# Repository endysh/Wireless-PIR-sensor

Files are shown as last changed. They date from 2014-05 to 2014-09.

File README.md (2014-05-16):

Wireless-PIR-sensor
===================

The project was stared with a goal of creating a low-cost wireless PIR sensor by using Arduino compatible hardware and enclosure from already available cheap, less than $5, PIR lights you can find on eBay, like the following 
http://www.ebay.com/sch/i.html?_from=R40&_sacat=0&_nkw=wireless+pir+light+battery&_sop=15

### Features
- custom Arduino compatible hardware
- nrf24L01 2.4 GHz wireless module for communication
- 2+ years run time with 2 AA batteries

### Images

Top<br>
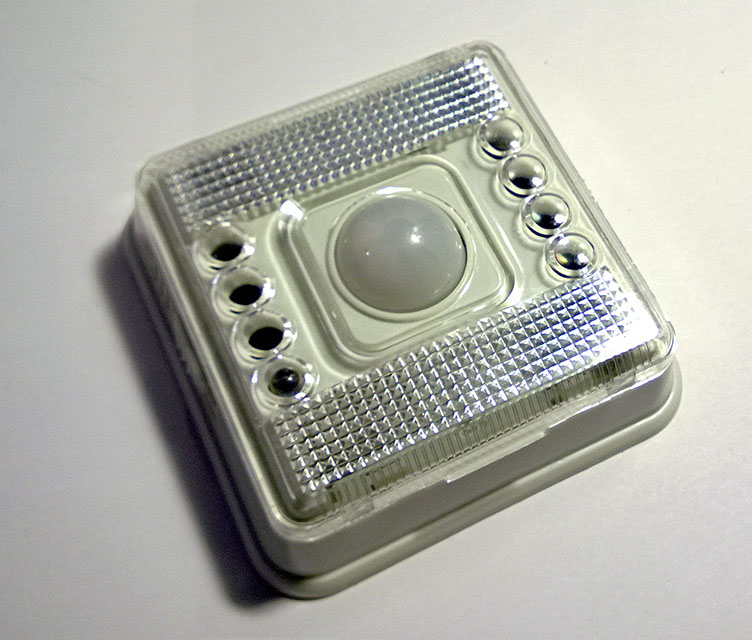
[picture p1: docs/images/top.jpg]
Top


Back with PCB visible<br>
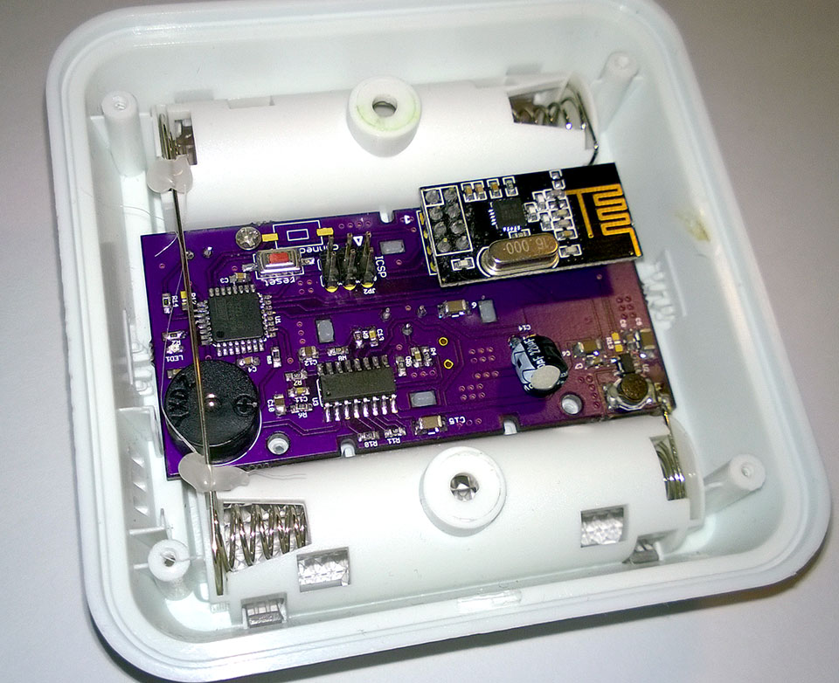
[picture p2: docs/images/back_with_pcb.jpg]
Back with PCB


Unpopulated 2-layer PCB, front and back<br>
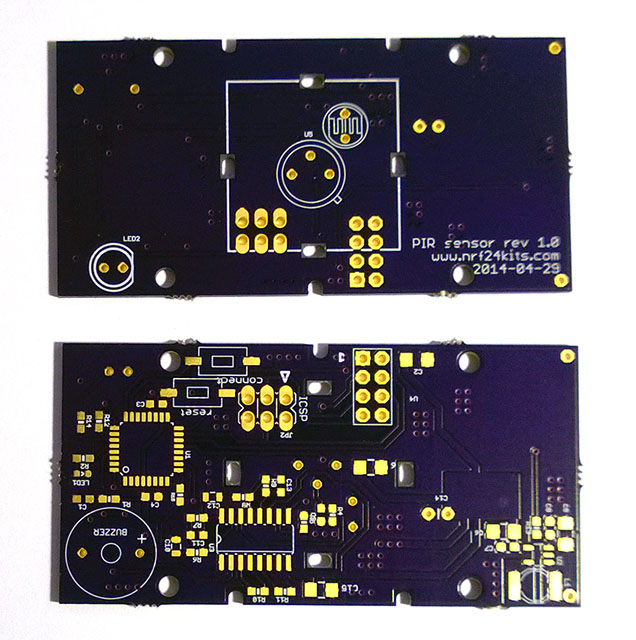
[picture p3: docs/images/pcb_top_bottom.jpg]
PCB top and bottom


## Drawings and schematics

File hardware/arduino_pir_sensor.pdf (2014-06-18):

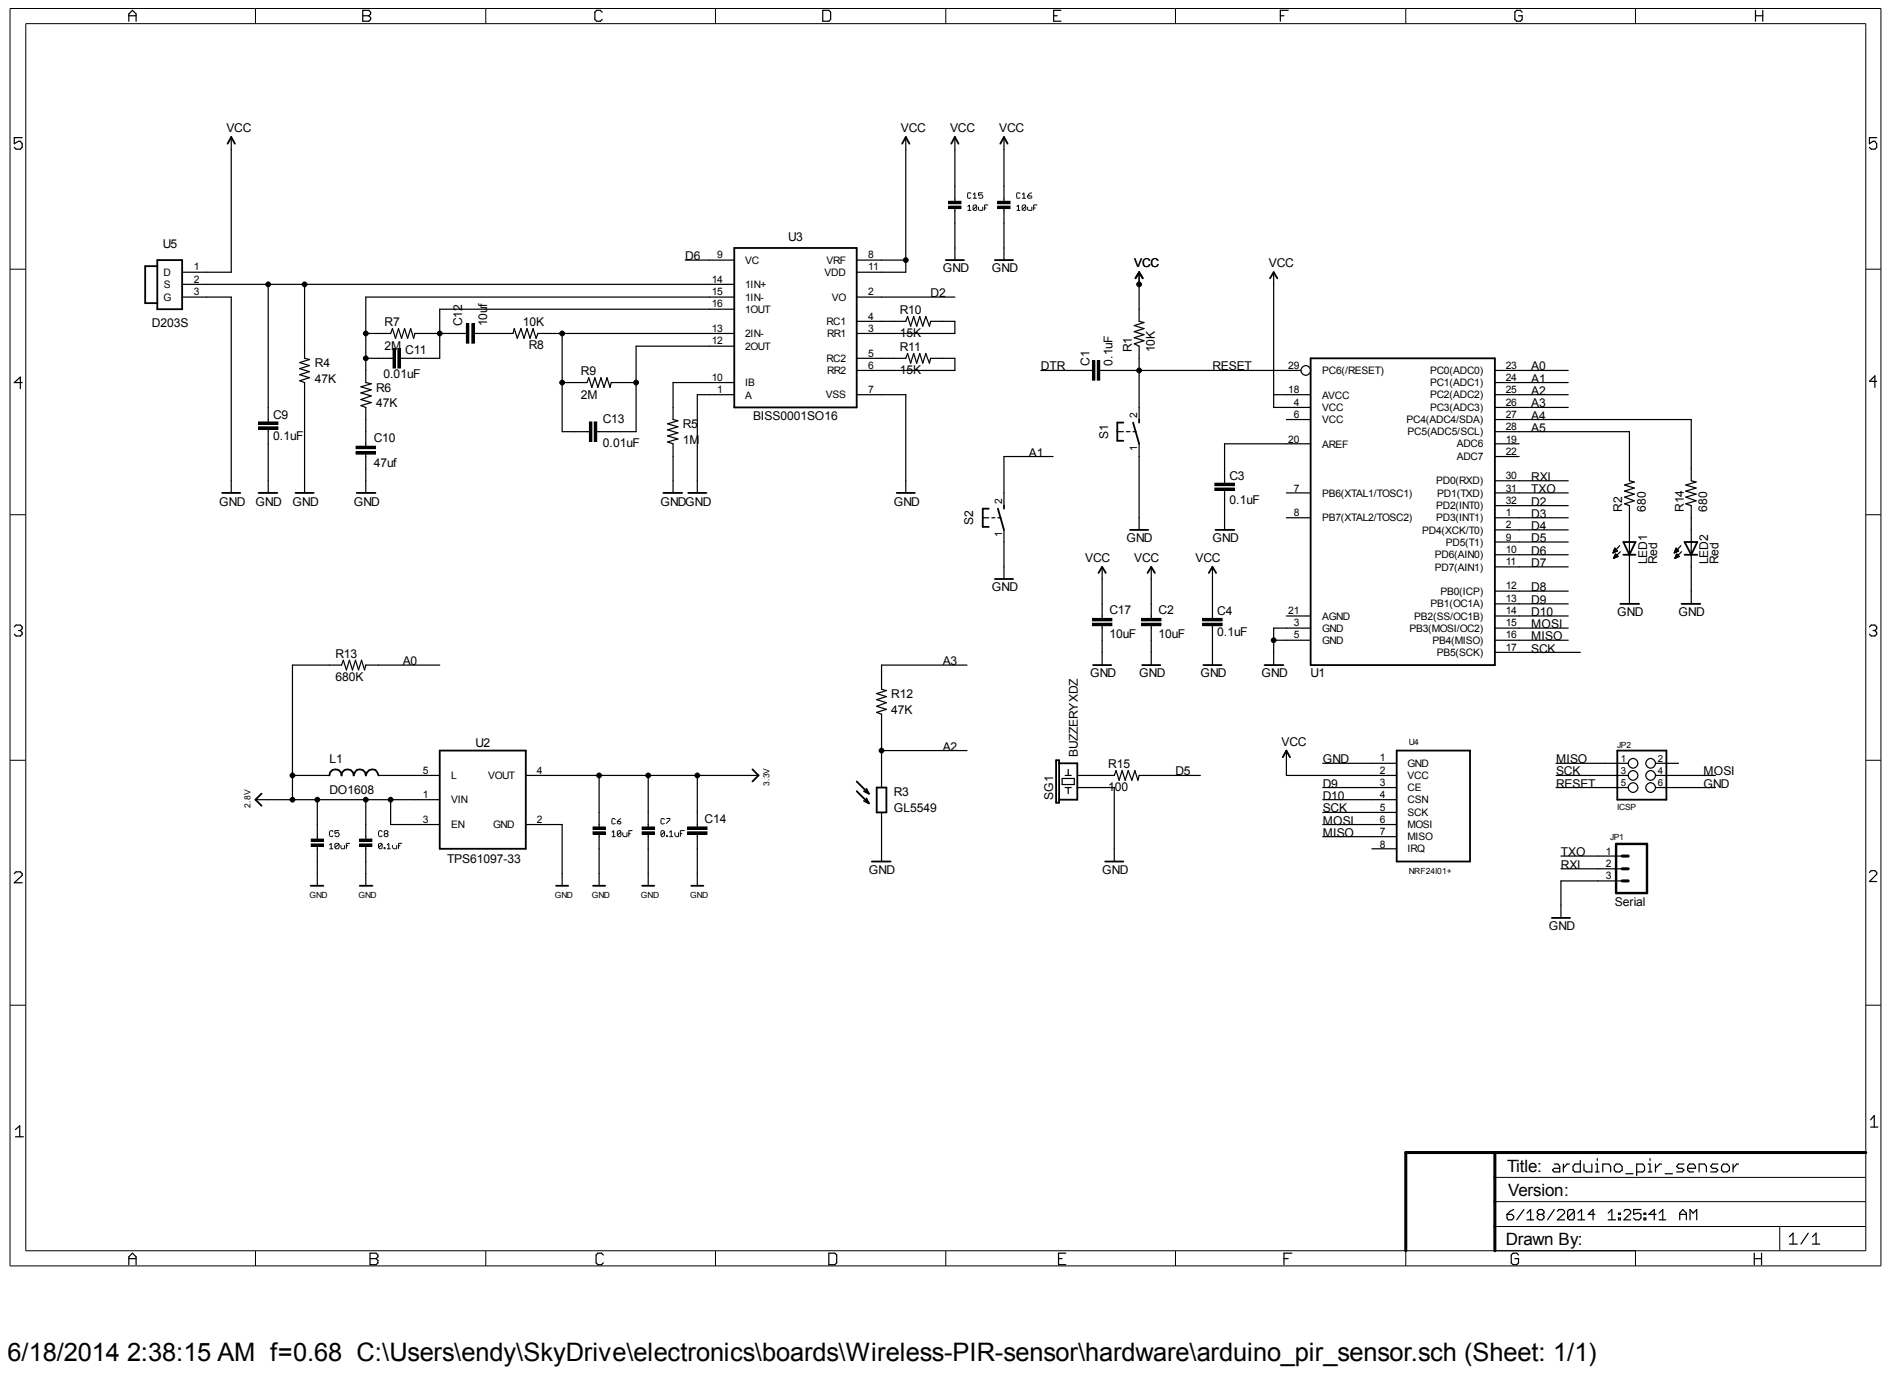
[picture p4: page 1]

1OUT 16

2OUT 12 2IN- 13

6/18/2014 2:38:15 AM f=0.68 C:\Users\endy\SkyDrive\electronics\boards\Wireless-PIR-sensor\hardware\arduino_pir_sensor.sch (Sheet: 1/1)

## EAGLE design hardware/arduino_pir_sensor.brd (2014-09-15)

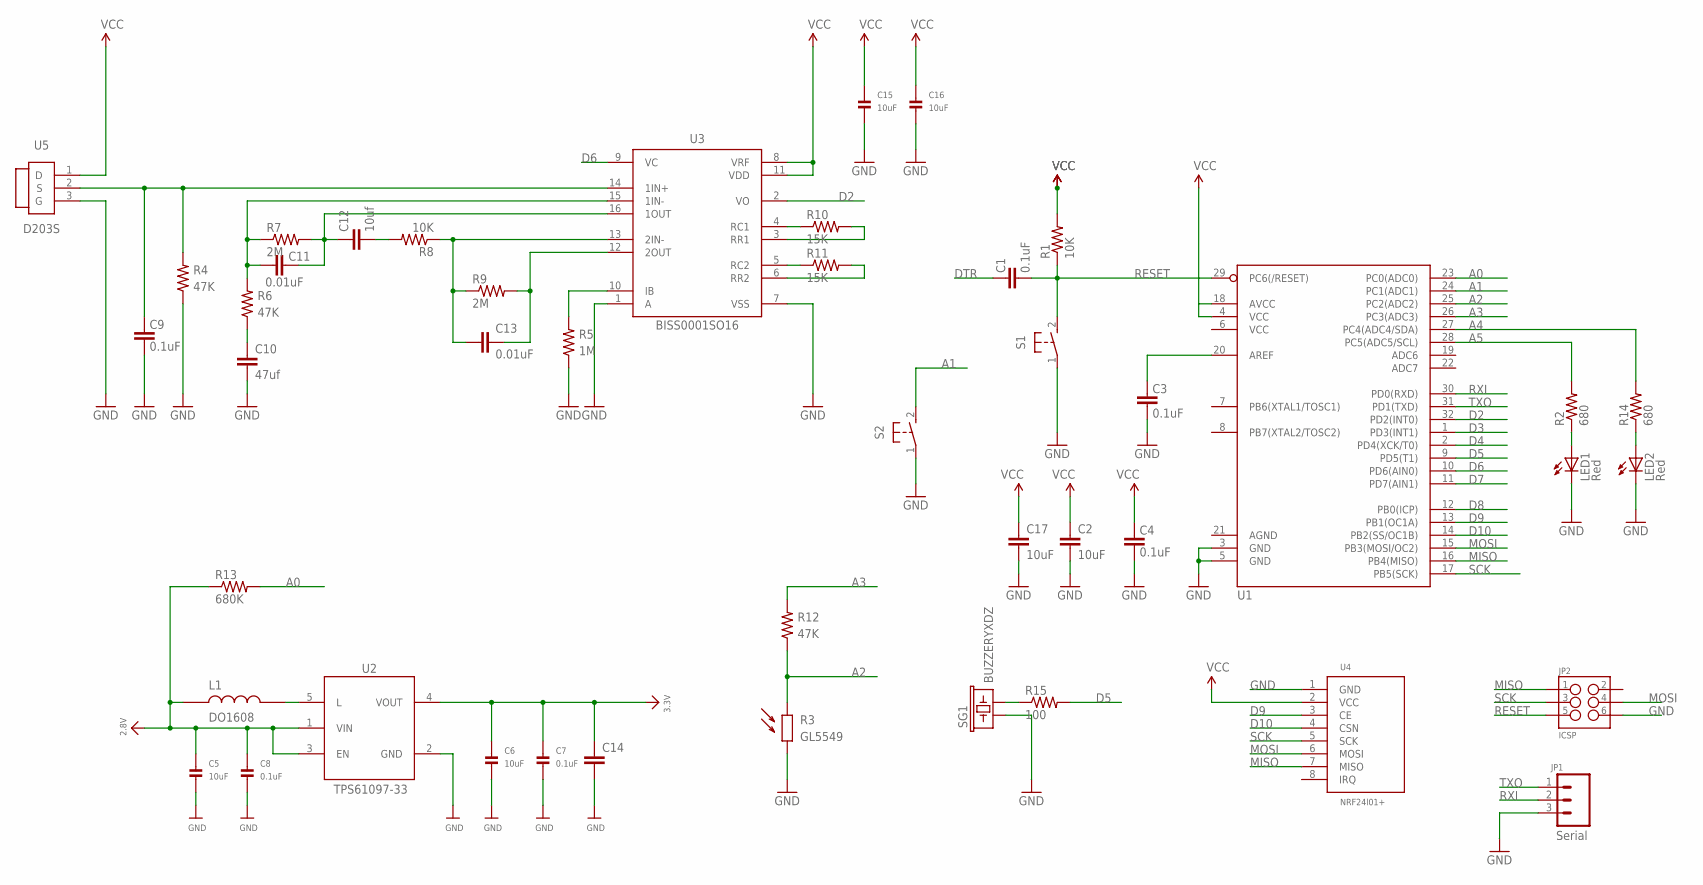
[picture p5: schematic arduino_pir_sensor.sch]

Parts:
C1, C3, C4, C9: 0.1uF; 0603-CAP; MPN 02016D104KAT2A
C2, C5, C6, C15, C16, C17: 10uF; 1206
C7, C8: 0.1uF; 0603
C10: 47uf; 0805
C11, C13: 0.01uF; 0603-CAP
C12: 10uf; 0805
C14: CAPPTH; CAP-PTH-SMALL
JP1: Serial; 1X03
JP2: ICSP; 2X3_POGO
L1: DO1608
LED1: Red; LED-0603
LED2: Red; LED5MM
R1, R8: 10K; 0603-RES
R2, R14: 680; 0603-RES
R3: GL5549; PHOTCELL
R4, R6, R12: 47K; 0603-RES
R5: 1M; 0603-RES
R7, R9: 2M; 0603-RES
R10, R11: 15K; 0603-RES
R13: 680K; 0603-RES
R15: 100; 0603-RES
S1, S2: TAC_SWITCH_SPST-6X3; TACTILE_SMD_6X3
SG1: BUZZERYXDZ; BUZZER-12MM-7.65
U1: ATMEGA328_SMT; TQFP32-08
U2: TPS61097-33; SOT-23-5L
U3: BISS0001SO16; SO-16
U4: NRF24L01+_MODULE; NRF24L01+MODULE
U5: D203S; TO5

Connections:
2.8V: C5.1, C8.1, L1.P$1 (1), R13.1, U2.1 (VIN), U2.3 (EN)
3.3V: C2.1, C4.2, C6.1, C7.1, C14.1, C15.1, C16.1, C17.1, R1.2, U1.4 (VCC), U1.18 (AVCC), U2.4 (VOUT), U3.8 (VRF), U3.11 (VDD), U4.2 (VCC), U5.1 (D)
A0: R13.2, U1.23 (PC0(ADC0))
A1: S2.2, U1.24 (PC1(ADC1))
A2: R3.P$1, R12.1, U1.25 (PC2(ADC2))
A3: R12.2, U1.26 (PC3(ADC3))
A4: R14.2, U1.27 (PC4(ADC4/SDA))
A5: R2.2, U1.28 (PC5(ADC5/SCL))
D2: U1.32 (PD2(INT0)), U3.2 (VO)
D3: U1.1 (PD3(INT1))
D4: U1.2 (PD4(XCK/T0))
D5: R15.2, U1.9 (PD5(T1))
D6: U1.10 (PD6(AIN0)), U3.9 (VC)
D7: U1.11 (PD7(AIN1))
D8: U1.12 (PB0(ICP))
D9: U1.13 (PB1(OC1A)), U4.3 (CE)
D10: U1.14 (PB2(SS/OC1B)), U4.4 (CSN)
DTR: C1.2
GND: C2.2, C3.1, C4.1, C5.2, C6.2, C7.2, C8.2, C9.1, C10.2, C14.2, C15.2, C16.2, C17.2, JP1.3, JP2.P$6 (6), LED1.C, LED2.K (C), R3.P$2, R4.1, R5.1, S1.1, S2.1, SG1.- (2), U1.3 (GND), U1.5 (GND), U2.2 (GND), U3.1 (A), U3.7 (VSS), U4.1 (GND), U5.3 (G)
MISO: JP2.P$1 (1), U1.16 (PB4(MISO)), U4.7 (MISO)
MOSI: JP2.P$4 (4), U1.15 (PB3(MOSI/OC2)), U4.6 (MOSI)
unnamed: L1.P$2 (2), U2.5 (L)
unnamed: C9.2, R4.2, U3.14 (1IN+), U5.2 (S)
unnamed: LED1.A, R2.1
unnamed: C3.2, U1.20 (AREF)
unnamed: R5.2, U3.10 (IB)
unnamed: C10.1, R6.1
unnamed: C11.2, R6.2, R7.1, U3.15 (1IN-)
unnamed: C11.1, C12.1, R7.2, U3.16 (1OUT)
unnamed: C12.2, R8.2
unnamed: C13.1, R8.1, R9.1, U3.13 (2IN-)
unnamed: C13.2, R9.2, U3.12 (2OUT)
unnamed: R11.1, U3.5 (RC2)
unnamed: R10.1, U3.4 (RC1)
unnamed: R10.2, U3.3 (RR1)
unnamed: R11.2, U3.6 (RR2)
unnamed: R15.1, SG1.+ (1)
unnamed: LED2.A, R14.1
RESET: C1.1, JP2.P$5 (5), R1.1, S1.2, U1.29 (PC6(/RESET))
RXI: JP1.2, U1.30 (PD0(RXD))
SCK: JP2.P$3 (3), U1.17 (PB5(SCK)), U4.5 (SCK)
TXO: JP1.1, U1.31 (PD1(TXD))

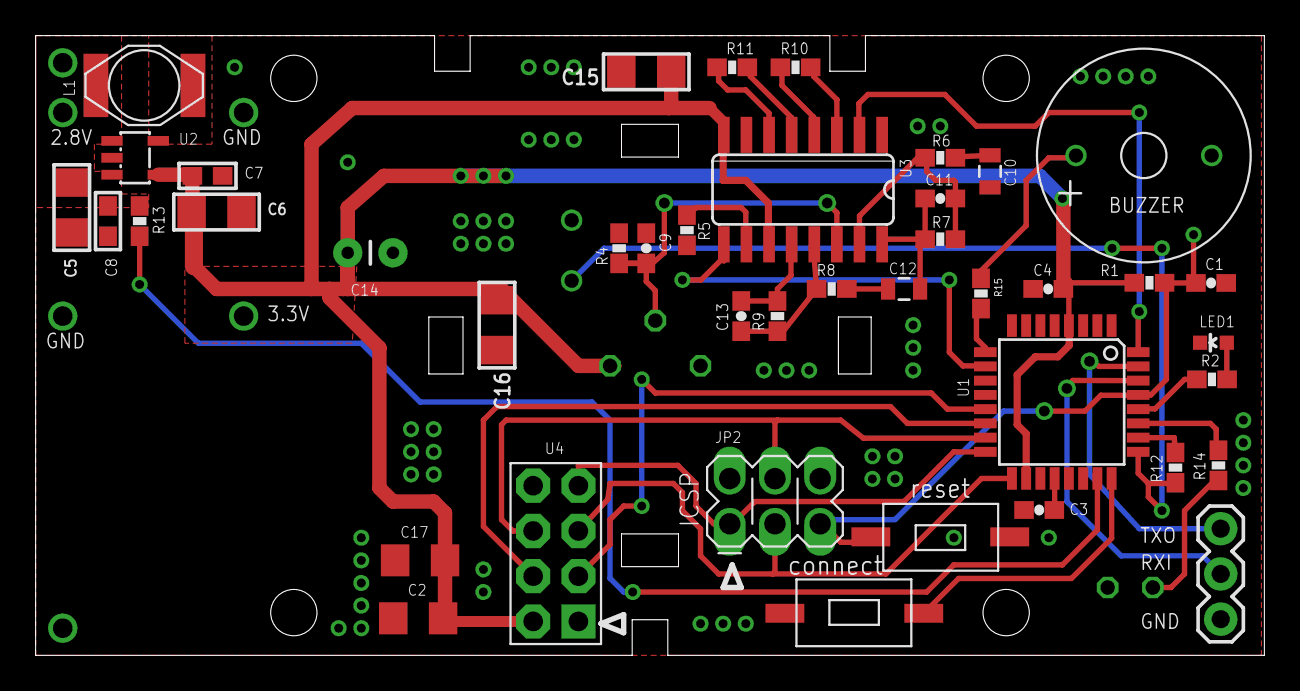
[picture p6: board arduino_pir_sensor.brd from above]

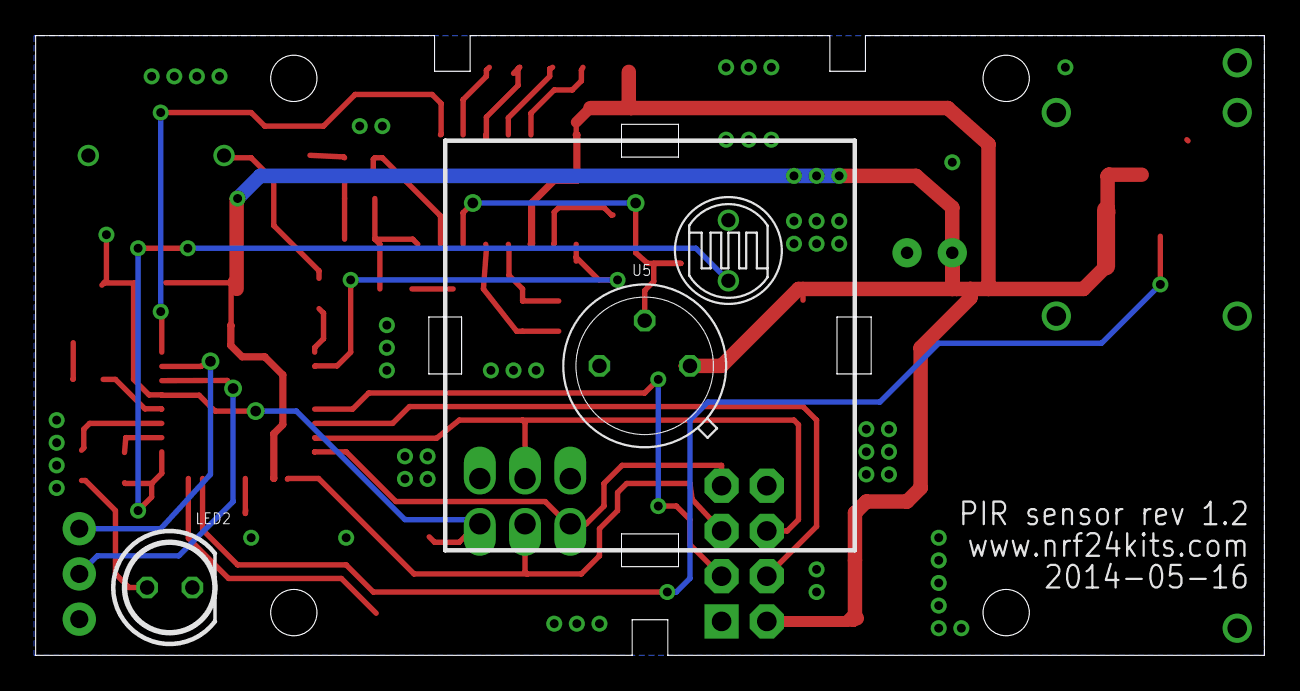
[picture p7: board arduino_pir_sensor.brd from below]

Board: 2 copper layers, 69.0 x 34.8 mm, 45 parts (3 on the bottom side), 37 nets.

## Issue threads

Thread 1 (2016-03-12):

Hardware

Dylantje, 2016-03-12:
Dear..
What is the hardware u use...
And what is the sketch?

RoelandK, 2016-03-12:
Hey,

Well a Pir sensor

Verstuurd vanaf mijn iPhone

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

endysh, 2016-03-12:
I reused the original sensor from the light

Thank you,
endy

-----Original Message-----
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

Dylantje, 2016-03-12:
and how did u use a sketch?
And how did u use the radio for mysensors?

endysh, 2016-03-13:
Hi,

Here is the example sketch for MySensors I wrote about 2 years ago.
https://github.com/endysh/Wireless-PIR-sensor/blob/master/firmware/MySensorNode/MySensorNode.ino
Most likely it is quite outdated already, I did not have a chance to adapt
it to the latest version of MySensors framework

Thank you.
Andrey

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

sijeffrey, 2016-10-10:
Hi Andrey,

I would really like to construct a wireless PIR like yours. Could I get a copy of the PCB? What format is it in?

Thanks,
Simon.

endysh, 2016-10-10:
Hi Simon,

The PCB files can be found under hardware folder.
There are three files:

arduino_pir_sensor.pdf - this is schematic in PDF format

Two others are in EAGLE CAD formats
arduino_pir_sensor.sch - schematics
arduino_pir_sensor.brd - PCB

You will need either to find a PCB manufacturer accepting EAGLE format or
export PCB to Gerber format which most PCB houses accept, using EAGLE CAD

Thank you,
Andrey

On Mon, Oct 10, 2016 at 11:07 AM, sijeffrey <notifications@github.com>
wrote:

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

Closed 2016-10-10.

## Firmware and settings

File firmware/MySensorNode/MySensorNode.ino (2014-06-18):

/*
  Wireless PIR sensor firmware for MySensor project
  revision 1.0
 
  Copyright (c) 2014, Andrey Shigapov, All rights reserved
 
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
*/

///////////////////////////////////////////////////////////////////////////////////////////////////////////////////
// Example wireless PIR sensor for MySensors IoT network . 
// For more information about MySensors project, please, visit http://www.mysensors.org/
// This program puts MCU in sleep mode and uses two interrupts to process events in order to save energy
// The first interrupt is generated by PIR sensor output connected to D2 input, the interrupt handler schedules 
// transmission of a report to MySensors gateway and disables PIR sensor for a number of WDT interrupts
// The second interrupt is generated by WDT and it fires about every 8 sec. 
// This interrupt handler decreases PIR sensor disable counter
///////////////////////////////////////////////////////////////////////////////////////////////////////////////////


#include <avr/sleep.h>
#include <avr/power.h>
#include <Sensor.h>
#include <SPI.h>
#include <EEPROM.h>  
#include <RF24.h>


#define ENABLE_SERIAL

//MySensor network node ID
#define NODE_RADIO_ID     0x51

//this sensor has only one child sensor
#define CHILD_ID          1

#define WDT_INTERVAL      8 //interval between WDT interrupts in seconds
#define REPORT_TIMEOUT    (60*60/WDT_INTERVAL) //make regular report interval 60 minutes

//defines number of WDT intervals (~8 sec) to keep PIR sensor disabled 
//after a report has been sent
#define PIR_DISABLE_INTERVAL 30 //~4 mins

#define BUTTON_PIN        A1 // Arduino Digital I/O pin for button/reed switch
#define PHOTO_CELL_PIN    A2 // Arduino Digital I/O pin for photo cell input
#define PHOTO_CELL_POWER  A3 // Arduino Digital I/O pin for photo cell power

#define STATUS_LED        A4 // the pin that the front LED is attached to
#define LED1              A5
#define BUZZER            5  // the pin that the Buzzer is attached to
#define PIR_ENABLE        6  // the pin that controls PIR output
#define PIR_INPUT         2  // the pin that connected to PIT output
#define BATTERY_LEVEL     A0 // the pin that connected to battery


uint16_t wdt_counter = 0;
uint16_t report_counter = 1;

uint8_t pir_disable_counter = 1;  //disable the sensor for the first 8 sec, let all transition precesses to settle down
uint8_t pir_enable_counter = 0;
uint8_t dataToSend = 0;
uint8_t dataSent = 0;

Sensor gw;


/////////////////////////////////////////////////////////////////
//  Returns:     Nothing.
//  Parameters:  None.
//
//  Description: PIR output signal Interrupt Service. 
//               This is executed when PIR sensor sense a movement,
//               it disables the PIR sensor for several WDT intervals
//               in order to conserve the energy
/////////////////////////////////////////////////////////////////
ISR(PIR_vect)
{
  if(pir_disable_counter == pir_enable_counter) {
    pir_disable_counter += PIR_DISABLE_INTERVAL;
    dataToSend++;
  }
}

/////////////////////////////////////////////////////////////////
//  Returns:     Nothing.
//  Parameters:  None.
//
//  Description: Watchdog Interrupt Service. This
//               is executed when watchdog times out, 
//               approximately every 8 seconds
/////////////////////////////////////////////////////////////////
ISR(WDT_vect)
{
  if(pir_disable_counter != pir_enable_counter) {
    pir_enable_counter += 1;
  }
  wdt_counter++;
}


/////////////////////////////////////////////////////////////////
//  Returns:     Nothing.
//  Parameters:  None.
//
//  Description: Enters the arduino into sleep mode.
/////////////////////////////////////////////////////////////////
void PowerDownSleep(void)
{
  //power down the radio
  gw.powerDown();
  
  set_sleep_mode(SLEEP_MODE_PWR_DOWN);   /* EDIT: could also use SLEEP_MODE_PWR_DOWN for lowest power consumption. */
  sleep_enable();
  
  //turn off peripherals
  volatile uint8_t old_ADCSRA = ADCSRA;
  ADCSRA = 0;
  PRR = 0
      | (1<<PRTWI)     // turn off TWI
      | (1<<PRTIM0)    // turn off Timer/Counter0
      | (1<<PRTIM1)    // turn off Timer/Counter1 (leave Timer/Counter2 on)
      | (1<<PRSPI)     // turn off SPI
      | (1<<PRUSART0)  // turn off USART (will turn on again when reset)
      | (1<<PRADC)     // turn off ADC
      | 0;

  //shut off BOD:
  MCUCR = _BV (BODS) | _BV (BODSE);  // turn on brown-out enable select
  MCUCR = _BV (BODS);        // this must be done within 4 clock cycles of above

  //-------------------------------------------
  // Now enter sleep mode.
  //-------------------------------------------
  sleep_cpu();
  
  // The program will continue from here after the WDT timeout
  // First thing to do is disable sleep.
  sleep_disable(); 
  
  // Re-enable the peripherals.
  power_all_enable();
  ADCSRA = old_ADCSRA;
  PRR = 0
#ifndef ENABLE_SERIAL
      | (1<<PRUSART0)  // turn off USART
#endif //#ifndef ENABLE_SERIAL
      | 0;
}


uint16_t readLightLevel()
{
  uint16_t Result = 0;
  
  pinMode(PHOTO_CELL_PIN, OUTPUT);
  pinMode(PHOTO_CELL_PIN, INPUT);
  
  pinMode(PHOTO_CELL_POWER, OUTPUT);
  digitalWrite(PHOTO_CELL_POWER, HIGH);
  delay(10);
  Result = 1024 - analogRead(PHOTO_CELL_PIN);

  // Setup the photo cell pins as input pins
  pinMode(PHOTO_CELL_POWER, INPUT);
  
  // Activate internal pull-down
  digitalWrite(PHOTO_CELL_POWER, LOW);
  digitalWrite(PHOTO_CELL_PIN, LOW);
  
  return Result;
}

void setup()
{
#ifdef ENABLE_SERIAL
  Serial.begin(115200);
  Serial.println("====================================");
  Serial.println("wireless PIR binary switch node v1.0");
  Serial.println("====================================");
  Serial.println("");
#endif //#ifdef ENABLE_SERIAL


  // Setup the button
  pinMode(PIR_ENABLE, OUTPUT);
  // Activate internal pull-up
  digitalWrite(BUTTON_PIN, HIGH);
  

  // Setup the button
  pinMode(BUTTON_PIN, INPUT);
  // Activate internal pull-up
  digitalWrite(BUTTON_PIN, HIGH);
  
  
  // Setup the photo cell pins as input pins
  pinMode(PHOTO_CELL_PIN, OUTPUT);
  pinMode(PHOTO_CELL_POWER, OUTPUT);
  // Activate internal pull-down
  digitalWrite(PHOTO_CELL_PIN, LOW);
  digitalWrite(PHOTO_CELL_POWER, LOW);
  

  // Setup battery level input pin
  pinMode(BATTERY_LEVEL, INPUT);
  
  // Setup the LED1
  pinMode(LED1, OUTPUT);
  // blink it
  digitalWrite(LED1, HIGH);
  delay(100);
  digitalWrite(LED1, LOW);
  
  
  // Set radioId to EEPROM if necessary
  if(0xff == EEPROM.read(EEPROM_RADIO_ID_ADDRESS)) {
    EEPROM.write(EEPROM_RADIO_ID_ADDRESS, NODE_RADIO_ID);
  }

  if(LOW == digitalRead(BUTTON_PIN)) {
    Serial.println("Erasing EEPROM settings");
    EEPROM.write(EEPROM_RADIO_ID_ADDRESS, 0xff);
    EEPROM.write(EEPROM_RELAY_ID_ADDRESS, 0xff);
    EEPROM.write(EEPROM_DISTANCE_ADDRESS, 0xff);
  }


  delay(200);
  gw.begin();
  
  // Register binary input sensor to gw (they will be created as child devices)
  // You can use S_DOOR, S_MOTION or S_LIGHT here depending on your usage. 
  // If S_LIGHT is used, remember to update variable type you send in below.
  gw.sendSensorPresentation(CHILD_ID, S_DOOR);  
  
  //////////////////////////////////////////////////////////////////////////
  //     Setup the WDT interrupt
  //////////////////////////////////////////////////////////////////////////
  // Clear the reset flag.
  MCUSR &= ~(1<<WDRF);
  
  // In order to change WDE or the prescaler, we need to
  // set WDCE (This will allow updates for 4 clock cycles).
  WDTCSR |= (1<<WDCE) | (1<<WDE);

  // set new watchdog timeout prescaler value
  WDTCSR = 1<<WDP0 | 1<<WDP3; // 8.0 seconds 
  
  // Enable the WD interrupt (note no reset).
  WDTCSR |= _BV(WDIE);
  
  
  //////////////////////////////////////////////////////////////////////////
  //     Setup PIR interrupts
  //////////////////////////////////////////////////////////////////////////
  attachInterrupt(0, PIR_vect, FALLING);

#ifdef ENABLE_SERIAL
  Serial.println("");
  Serial.println("================================");
  Serial.println("Setup complete. Sensor is ready");
  Serial.println("================================");
  Serial.println("");
  delay(200);
#endif //#ifdef ENABLE_SERIAL
  
}


//  Check if digital input has changed and send in new value
void loop() 
{
  //enable/disable PIR
  digitalWrite(PIR_ENABLE, (pir_disable_counter == pir_enable_counter)?1:0);
  
  //send motion detected report
  if(dataToSend != dataSent) {
    // Send in the new value
#ifdef ENABLE_SERIAL
    Serial.println("=================================");
    Serial.println("send motion detected event");
#endif //#ifdef ENABLE_SERIAL
    gw.sendVariable(CHILD_ID, V_TRIPPED, "1");  
    dataSent = dataToSend;
  }
 
  // send regular report
  if(report_counter == wdt_counter) {
    report_counter += REPORT_TIMEOUT;
    
    uint16_t batteryLevel = analogRead(BATTERY_LEVEL);
    uint16_t lightLevel = readLightLevel();
#ifdef ENABLE_SERIAL
    Serial.println("=================================");
    Serial.println("send a report");
    Serial.print("battery level: ");
    Serial.println(batteryLevel);
    Serial.print("light level: ");
    Serial.println(lightLevel);
    Serial.println("go to sleep");
#endif //#ifdef ENABLE_SERIAL

    gw.sendBatteryLevel(batteryLevel);
    gw.sendVariable(CHILD_ID, V_LIGHT_LEVEL, lightLevel);
  }


#ifdef ENABLE_SERIAL
  delay(100);
#endif //#ifdef ENABLE_SERIAL
  
  //power down the sensor till next interrupt
  PowerDownSleep();
  
#ifdef ENABLE_SERIAL
  Serial.println("woke up");
#endif //#ifdef ENABLE_SERIAL

} 

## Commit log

2014-05-16 - initial check in - revision 1.0
    This program sends a single byte command with ASCII value 'o' to the preconfigured node
    when motion is detected and reported by PIR mode, then waits for 5 sec before it reads PIR sensor output again.
    No power saving techniques is used in this version, thus the current power consumption makes it not very suitable for
    operation from a battery
    [arduino_pir_sensor.brd, arduino_pir_sensor.sch]
2014-05-16 - pdf image for schematics added - frame to schematics added
    [arduino_pir_sensor.sch]
2014-05-16 - cutout in ground planes on all PCB layers added below wireless module antenna - serial communication connector added
    [arduino_pir_sensor.brd, arduino_pir_sensor.sch]
2014-05-16 - labels font type changed to vector
    [arduino_pir_sensor.brd]
2014-05-16 - schematic pdf file updated
    [arduino_pir_sensor.brd, arduino_pir_sensor.sch]
2014-05-18 - switching to power saving techniques
    // This program puts MCU in sleep mode and uses two interrupts to process events in order to save energy
    // The first interrupt is generated by PIR sensor output connected to D2 input, the interrupt handler schedules
    // transmission of a single byte command with ASCII value of 'o' and disables PIR sensor for a number of WDT interrupts
    // The second interrupt is generated by WDT and it fires about every 8 sec.
    // This interrupt handler decreases PIR sensor disable counter
2014-05-18 - extra power line capacitor added - "connect" button moved away from the mounting screw
    [arduino_pir_sensor.brd, arduino_pir_sensor.sch]
2014-06-10 change value of the photo cell divider resistor to 47K from 510K
    [arduino_pir_sensor.brd, arduino_pir_sensor.sch]
2014-06-11 Example wireless PIR sensor for MySensors IoT network initial checkin, does not send battery and light levels yet
2014-06-13 - send battery level and light level reports every 60 minutes
2014-06-18 - resistor values fixed
    [arduino_pir_sensor.brd, arduino_pir_sensor.sch]
2014-09-15 - minor reroute power lines for BISS0001 - contact pads for external power supply added
    [arduino_pir_sensor.brd]

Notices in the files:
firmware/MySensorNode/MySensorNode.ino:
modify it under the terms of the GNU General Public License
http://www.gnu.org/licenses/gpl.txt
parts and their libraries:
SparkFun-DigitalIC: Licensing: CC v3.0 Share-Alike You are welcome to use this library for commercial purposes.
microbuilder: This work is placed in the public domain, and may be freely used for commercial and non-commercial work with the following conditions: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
